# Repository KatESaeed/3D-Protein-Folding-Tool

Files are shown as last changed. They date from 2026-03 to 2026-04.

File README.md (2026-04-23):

# 3D-Protein-Folding-Tool
This tool is designed to assist instructors in demonstrating protein folding based on the chemistry of the amino acid side chains. We have provided STL files of all 20 human amino acid side chains and a clamp designed to attach to the side chains and a bendy tube. We have also included our procedure and the software used to create the side chain files. We recommend downloading all software before following the procedure.

**Bendy tube link:** https://shop.3dmoleculardesigns.com/products/modeling-ties

# Abstract
Three-dimensional (3D) printing technology provides new opportunities to improve conceptual understanding of complex and conceptual topics in chemistry and biology through developing interactive educational tool. Understanding how the primary structure of amino acid sequence dictates the higher order protein structures is important and of interests to structural biology and biochemistry. Visualizing how amino acid side chain chemistry influences protein folding using traditional two-dimensional representations can be difficult. The objective of this research was to develop a 3D-printed educational tool that demonstrates how amino acid side chain chemistry affects protein folding in higher order structures. Amino acid side chains were printed for biological pH conditions and a clamp and snap-joint mechanism were designed to attach the side chains to a flexible tube representing the protein backbone. The side chains were printed in different colors to represent their polarity and charge. The design was done while keeping in mind the importance of size, dimensional accuracy, structural strength, adaptability, and modularity needed in a practical educational tool. The resulting modular model provides a hands-on method for demonstrating the influence of amino acid side chain chemistry on protein structure and highlights the potential of 3D printing to enhance interactive STEM education.

# Software
## ChemDraw and Chem3D
ChemDraw is a very helpful tool to create 2D models of amino acids and other molecules. Chem3D can be used to display molecules in 3D. These programs may require separate downloads.

**Download:** https://connect.revvitysignals.com/sitesubscription/

## UCSF Chimera
Chimera is a powerful visualizng tool that can be used for structural analysis of proteins and other biological molecules. We use it to set the visualizing style of our molecules including the way atoms are displayed and the size and thickness of the atoms and bonds.

**Download:** https://www.cgl.ucsf.edu/chimera/download.html

## Blender
Blender is a 3D computer graphic software. We will use it to build the 3D model (mesh) that can be used for 3D printing.

**Download:** https://download.blender.org/release/Blender2.79/ 

**(Download the 2.79b version)**

## MolPrint
MolPrint is an add-on to Blender that makes minipulating and preparing the molecules for 3D printing much easier. It is created by Dr. Paul Paukstelis.

**Download:** https://github.com/paukstelis/MolPrint

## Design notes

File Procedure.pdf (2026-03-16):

## Current Procedure

This procedure will allow you to prepare an STL file of an amino acid side chain. It does not currently include the steps to print the finished file.
ChemDraw:
1. Open ChemDraw.
2. Select File -> Open Templates -> Amino Acid Side Chains.
3. Select the side chain of the amino acid you would like to print. They are organized in a table by their three-letter abbreviation.
4. Under the tools bar, select Lasso.
5. Use the lasso tool to highlight the amino acid side chain.
6. Copy the highlighted side chain using CTRL+C or right click -> Copy. You will paste the amino acid structure directly into Chem3D.
Chem3D:
7. Open Chem3D.
8. On the right side under “ChemDraw - LiveLink” paste the side chain using CTRL+V or right click -> Paste.
9. In the top bar, select Calculations -> MM2 -> Minimize Energy.
10. Select Run.
11. Select File -> Save As.
12. Save your file with “SYBYL2 (*.mol2)” as the file type.
Chimera:
13. Open Chimera.
14. Select File -> Open.
15. Select your .mol2 file.
16. Select Select -> Chemistry -> Element -> H. (Skip if you want to show hydrogen in your model).
17. Select Actions -> Atoms/Bonds -> Hide. (Skip if you want to show hydrogen in your model).
18. Select Favorites -> Command Line.
19.Copy the following into the command line located at the bottom of the app:

represent b+s
~disp solvent
setattr M ballScale 0.3

setattr M stickScale 1.2
bondcolor grey
setattr p drawMode 1
20. Select File -> Export Scene
21. Save your file with “VMRL [.wrl, .vmrl]” as the file type. Blender:
22. Open Blender.
23.Click “x” to delete the cube that is in the file by default.
24. In the side bar, select MolPrint.
25. Select Open VMRL.
26. Select your .vmrl or .wrl file.
27. Select Open VMRL2.
28. Input the following settings (if there are double bonds):
double bond scale (DB scale) = 0.40
double bonds separation (DB separ) = 1.41
29. If there are any double bonds in the amino acid, right click where the double bond should be and select Double Bonds on the left side.
30. On the carbon that attaches to the backbone, any attached hydrogen bonds or atoms.
31. Select File -> Export -> Stl (.stl).
32. Save your file.

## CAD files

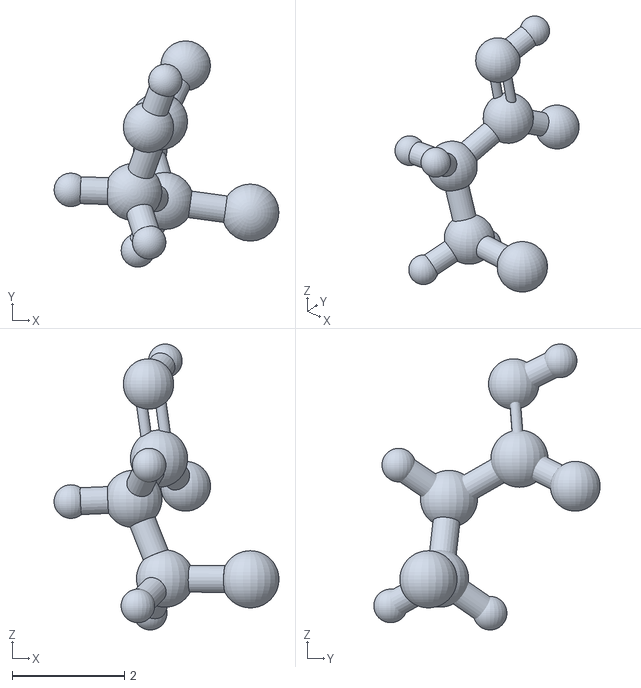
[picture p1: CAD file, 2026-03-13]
Acidic/glutamate.stl
4.01 x 4.04 x 5.10

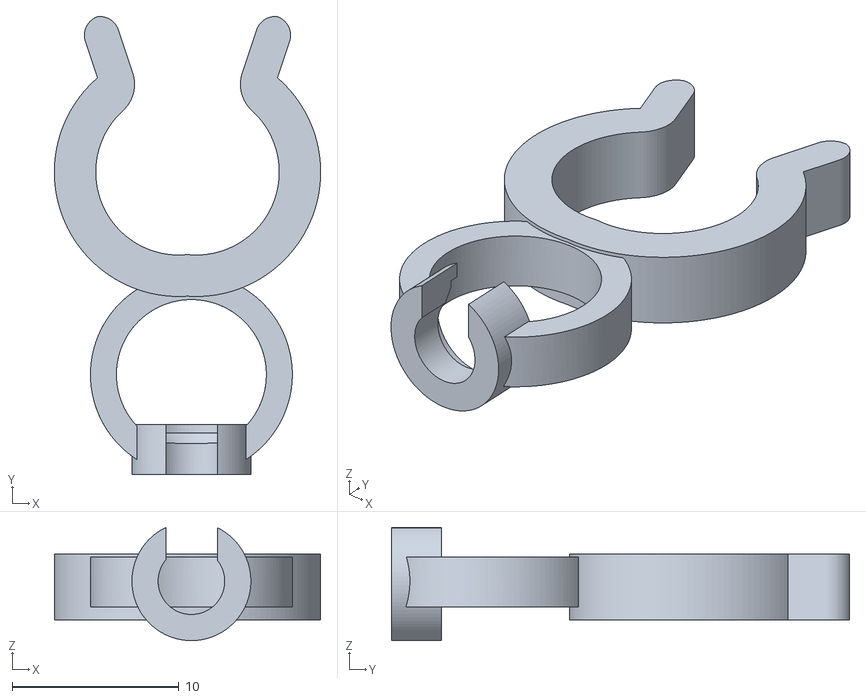
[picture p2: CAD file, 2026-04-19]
AttachmentMechanism.stl
16.0 x 27.5 x 6.79

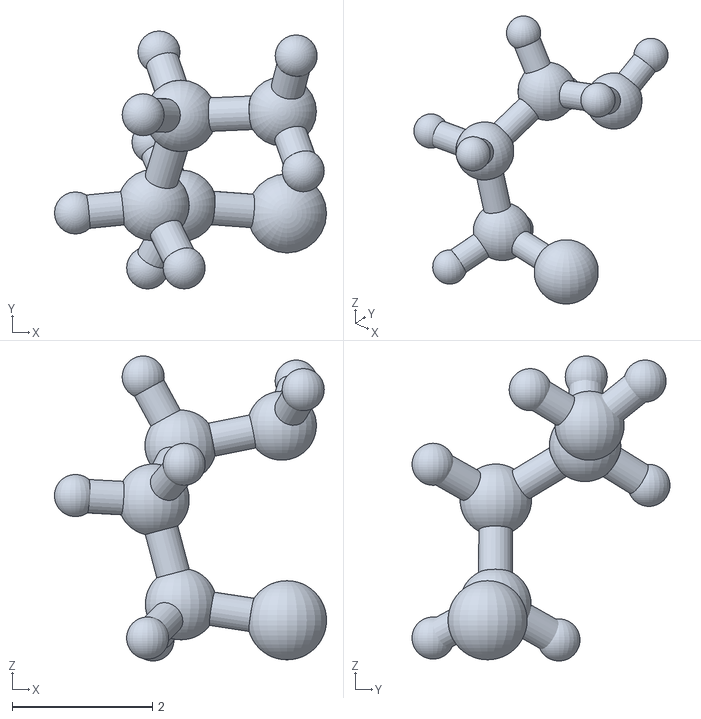
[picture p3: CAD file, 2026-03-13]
Basic/lysine.stl
3.88 x 3.68 x 4.35

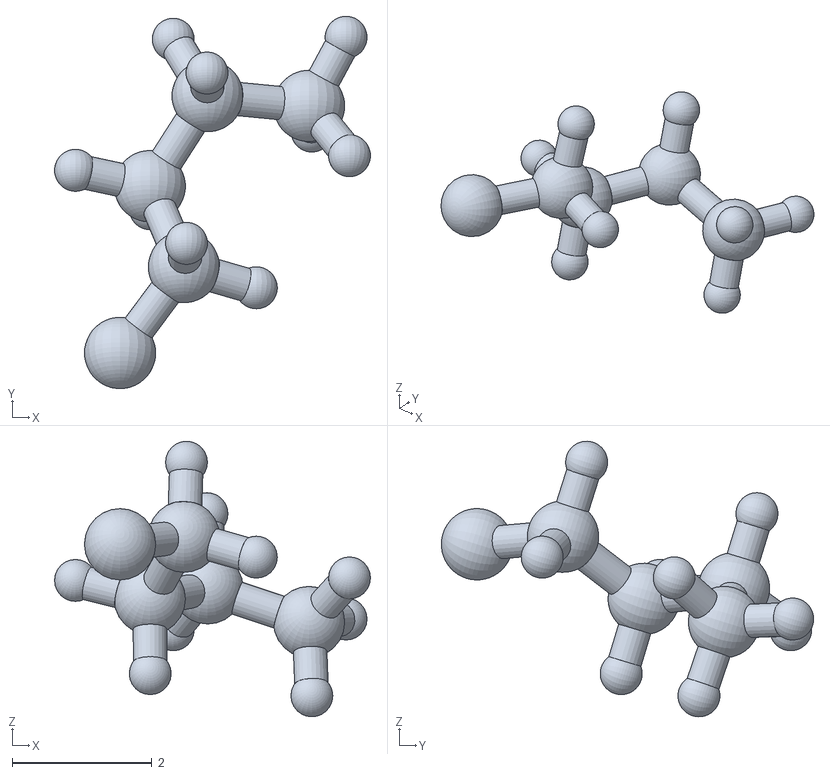
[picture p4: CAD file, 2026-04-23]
Nonpolar/proline.stl
4.52 x 5.32 x 3.94

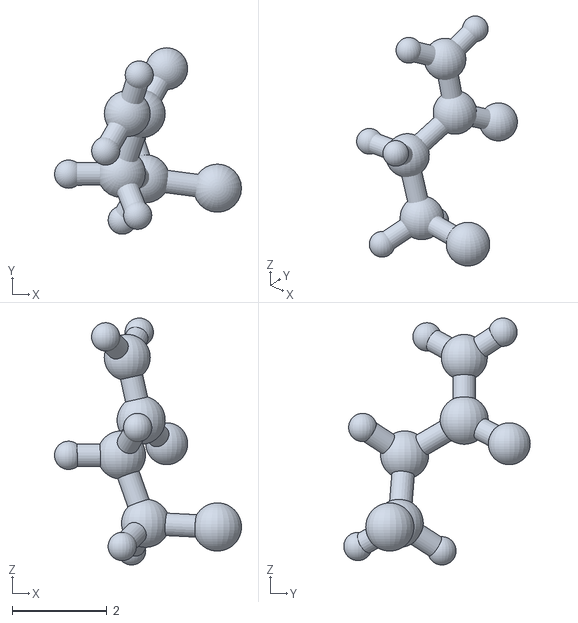
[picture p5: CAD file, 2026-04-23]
Polar/glutamine.stl
3.96 x 3.95 x 5.23

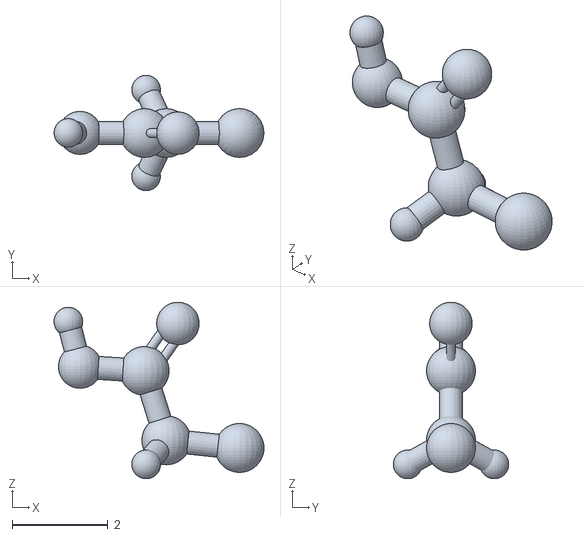
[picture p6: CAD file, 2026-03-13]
Acidic/aspartate.stl
4.38 x 2.41 x 3.68

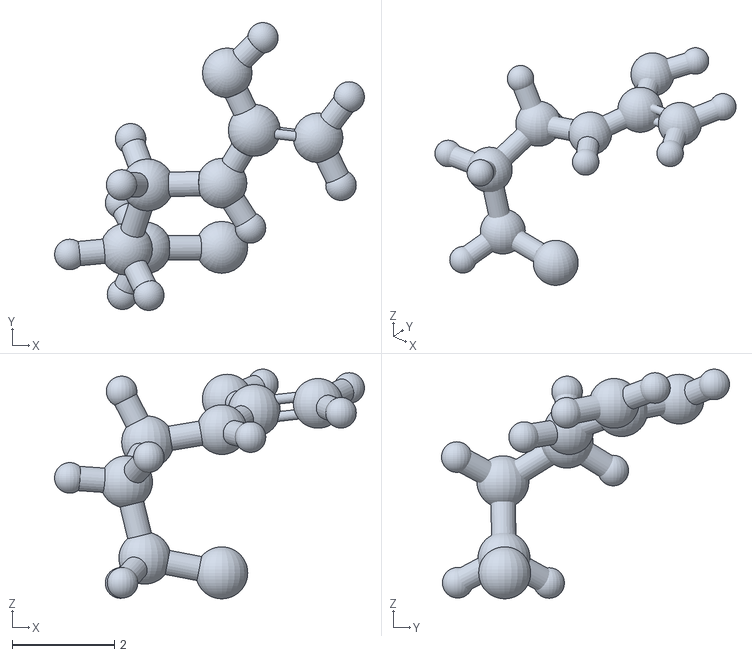
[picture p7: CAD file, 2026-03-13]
Basic/arginine.stl
6.08 x 5.65 x 4.50

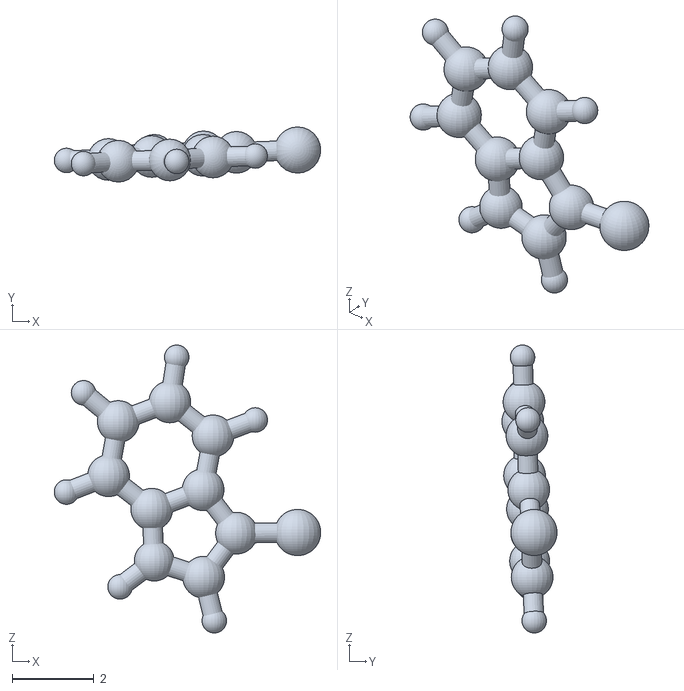
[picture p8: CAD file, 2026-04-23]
Nonpolar/tryptophan.stl
6.51 x 1.35 x 7.03

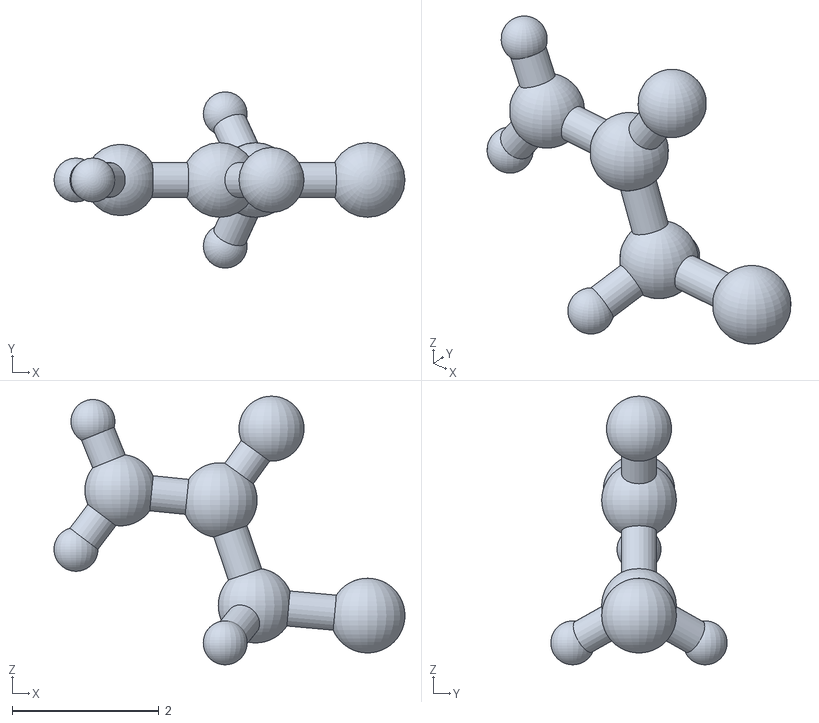
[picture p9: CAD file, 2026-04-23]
Polar/asparagine.stl
4.79 x 2.41 x 3.67

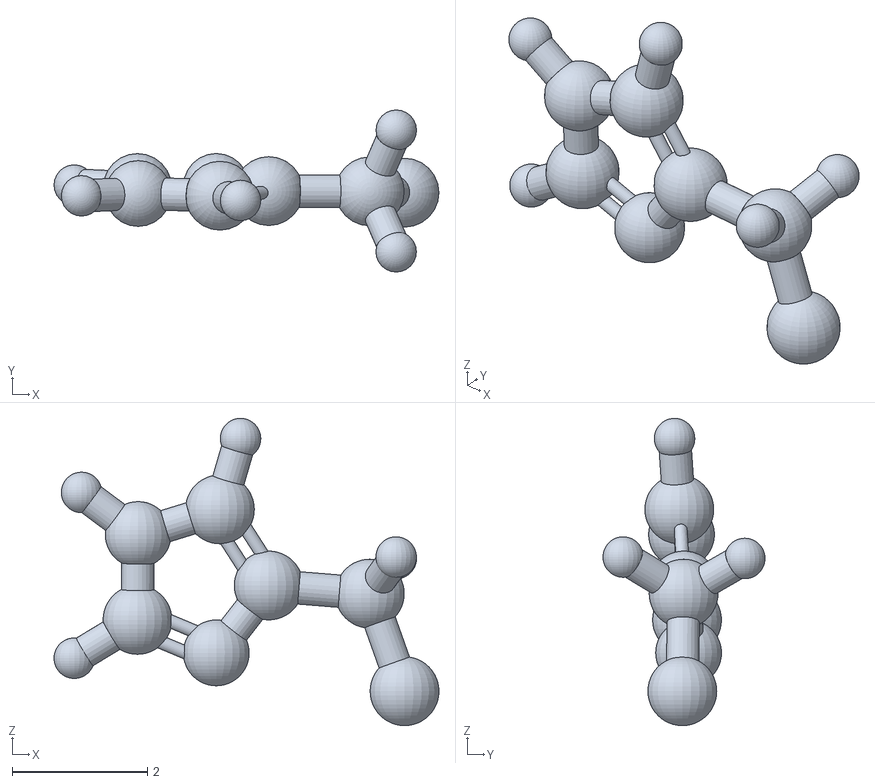
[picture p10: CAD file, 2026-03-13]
Basic/histidine.stl
5.70 x 2.40 x 4.55

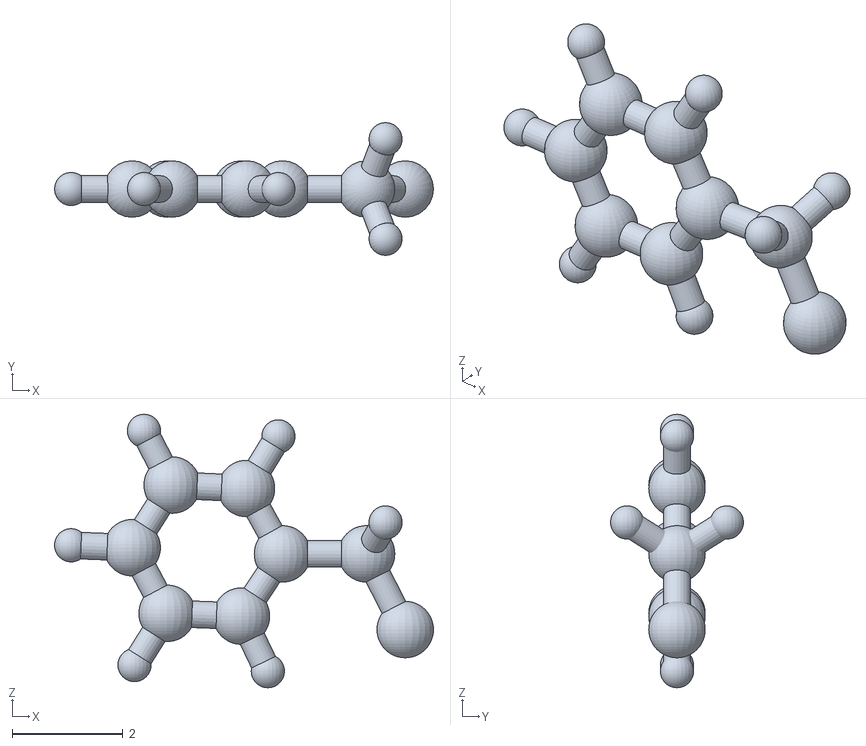
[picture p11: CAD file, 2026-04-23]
Nonpolar/phenylalanine.stl
6.84 x 2.40 x 4.94

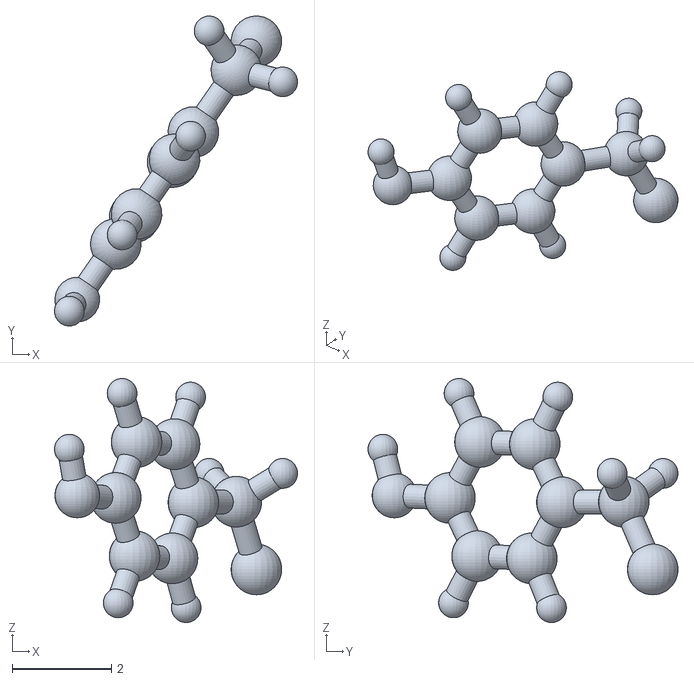
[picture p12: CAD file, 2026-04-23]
Polar/tyrosine.stl
4.89 x 6.23 x 4.91

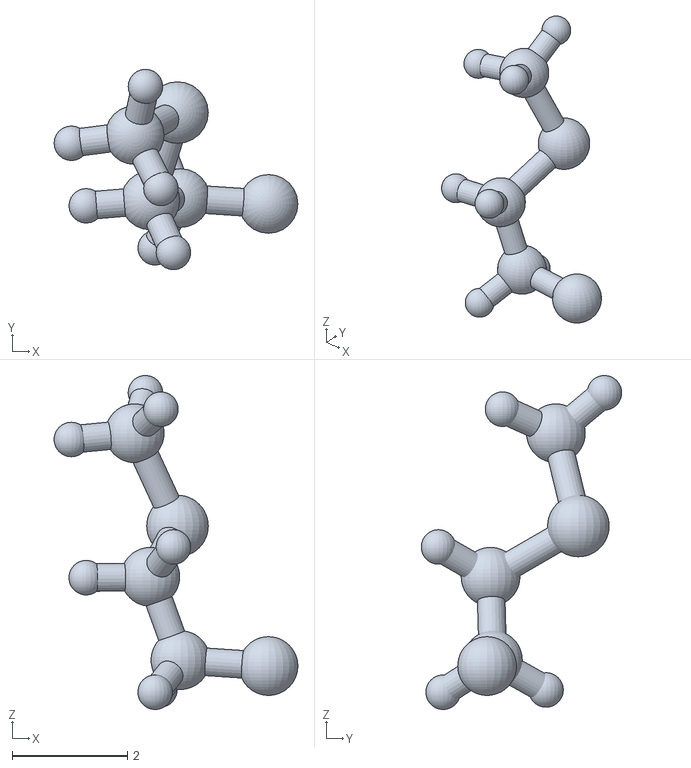
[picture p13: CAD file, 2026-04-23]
Nonpolar/methionine.stl
4.23 x 3.48 x 5.80

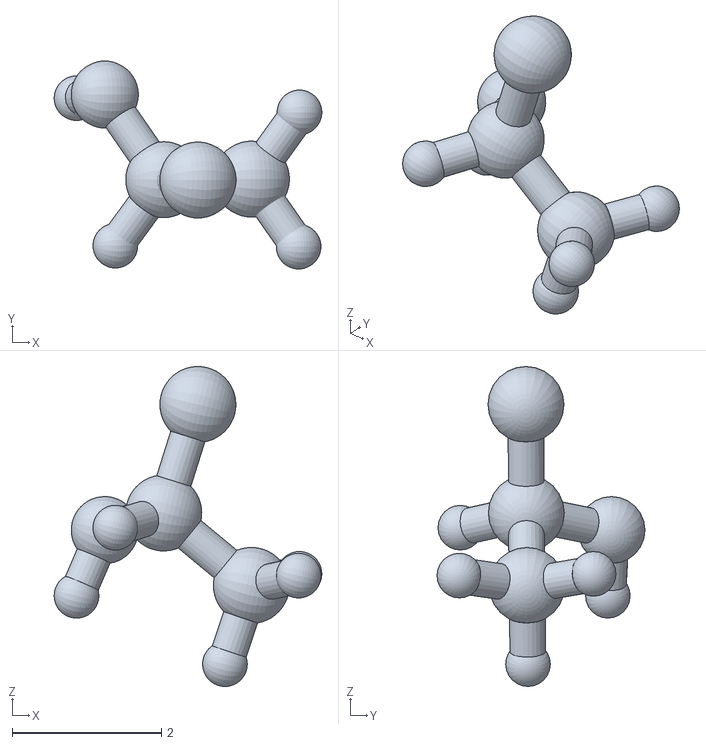
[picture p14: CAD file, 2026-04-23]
Polar/threonine.stl
3.59 x 2.79 x 4.29

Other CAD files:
Nonpolar/isoleucine.stl
Polar/serine.stl
Nonpolar/valine.stl
Polar/cysteine.stl
Nonpolar/alanine.stl
Nonpolar/glycine.stl
Nonpolar/leucine.stl

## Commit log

2026-03-16 Rename Amino Acid Side Chain Procedure.pdf to Procedure
2026-03-16 Create STL-files
2026-04-19 Rename Joint5 v2.stl to AttachmentMechanism.stl
    [AttachmentMechanism.stl]
